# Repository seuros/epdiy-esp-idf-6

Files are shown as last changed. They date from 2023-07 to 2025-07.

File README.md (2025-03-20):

  

EPDiy E-Paper Driver
=======================================

EPDiy is a driver board which talks to affordable E-Paper (or E-Ink) screens, which are usually sold as replacement screens for E-Book readers. Why are they interesting?

* Easy on the eyes and paper-like aesthetics
* No power consumption when not updating
* Sunlight-readable

Ready-made DIY modules for this size and with 4bpp (16 Grayscale) color support are currently quite expensive and / or slow.
The EPDiy controller can drive the bare display modules, e.g. from old e-Readers, which are available for 20$ (small) / 30$ (large) on ebay!
Additionally, since it is based on the ESP32S3 (V7) / ESP32 (V2-V6) microcontroller, it features WiFi and Bluetooth connectivity.

The EPDiy driver board targets a range of E-Paper displays, as shown in the table below.
As the driving method for all matrix-based E-ink displays is more or less the same, only the right connector and timings are needed.
The current V7 board has three different display connectors, other display will require an adapter board.

The controller is optimized for the use with LiPo batteries, featuring a LiPo charger and ultra-low deep sleep current.

This project supports a driver for the ESP-IDF and Arduino. For installation instructions, please refer to the [documentation](https://epdiy.readthedocs.io/en/latest/getting_started.html#getting-your-board).
Note that for epdiy V7, update speeds are significantly lower when using the Arduino IDE, because it does not allow to change
the sub-optimal cache configuration.

Get Inspired
------------

The `examples` directory contains some example applications like a weather station or a screen diagnostic test. 
If you want to build something more useful though, how about:

- A serial terminal for connecting to a raspberry pi: [video](https://cdn.hackaday.io/files/1681937195969312/terminal_demo.mp4) [repository](https://github.com/vroland/epdiy-terminal)]
- A Music Player Daemon (MPD) dashboard: [repository](https://github.com/vroland/epdiy-mpd)]
- An e-Paper picture frame: [video](https://www.youtube.com/watch?v=r7AcNQsSZUw)
- And more to come!

Building It
-----------

On the [EPDiy Hardware Page](https://vroland.github.io/epdiy-hardware/), you'll find a list of all boards and variants, adapters, and helpers.
Next to each board, there are manufacturing files (gerbers), Bill of Materials (BoM), part placement files,
and 3D models ready to use!

demo image

For ordering from JLCPCB for example, ordering is as easy as downloading the zipped gerbers, BoM, and placement file
and uploading them. The process is very similar for other manufacturers, check your vendor's documentation for details.
Don't forget to oder adapters if the board doesn't have connectors for your specific display.

The current latest version is epdiy V7, beased on the ESP32S3. 
Older versions are also available on the hardware page.

#### Contributing Hardware

Want to contribute your own board variant or adapter? 
Check out the [epdiy-hardware repository](https://github.com/vroland/epdiy-hardware) for instructions.

Gettings Started
----------------

For instructions and more information visit the [documentation](https://epdiy.readthedocs.io/en/latest/getting_started.html)!

Join the Discussion
----------------

 -  Matrix Community: +epdiy:matrix.vroland.de
 - Slack: See badge

Displays
--------

|Name |Size |Resolution|Compatible|Connector|Pin count|Compatible since pcb version|Notes
| --: | --: | --: | --: | --: | --: | --: | --: |
| ED060SC4 | 6"  | 800 x 600<br>167 PPI | yes, tested | FH26W-39S-0.3SHW(60) | 39  | v2  | |
|ED097OC4|9.7"|1200 x 825<br>150 PPI|yes, tested|XF2M-3315-1A|33|v2|Cheap, inferior contrast
|ED097TC2|9.7"|1200 x 825<br>150 PPI|yes, tested|XF2M-3315-1A|33|v2|Slightly higher price, better contrast
|ED097OC1|9.7"|1200 x 825<br>150 PPI|yes (should work)|XF2M-3315-1A|33|v2|Cheap, inferior performance
|ED047TC1|4.7"|960 x 540<br>234 PPI|yes, tested|40-pin|40|LILYGO 4.7" EPD|Supported only by 4.7" e-paper board by LILYGO
| ED050SC5 | 5" | 600 x 800<br>200 PPI | yes, tested | THD0510-33CL-GF | 33 | v5 |
| ED050SC3 | 5" | 600 x 800<br>200 PPI | yes (should work) | THD0510-33CL-GF | 33 | v5 |
| ED133UT2 | 13.3" | 1600 x 1200<br>150 PPI | yes, tested | adapter board | 39 | v2 | Adapter Board required, also PENG133D
| ED060XC3 | 6" | 758 x 1024<br>212 PPI | yes, tested | THD0515-34CL-SN | 34 | v5 | Cheapest, good contrast and resolution
| ED060XD4 | 6"  | 758 x 1024<br>212 PPI | yes, tested | THD0515-34CL-SN | 34 | v5 |
| ED060XC5 | 6"  | 758 x 1024<br>212 PPI | yes (should work as ED060XC3) | THD0515-34CL-SN | 34 | v5 |
| ED060XD6 | 6"  | 758 x 1024<br>212 PPI | yes (should work as ED060XC3) | THD0515-34CL-SN | 34 | v5 |
| ED060XH2 | 6"  | 758 x 1024<br>212 PPI | yes (should work as ED060XC3) | THD0515-34CL-SN | 34 | v5 |
| ED060XC9 | 6"  | 758 x 1024<br>212 PPI | yes (should work as ED060XC3) | THD0515-34CL-SN | 34 | v5 |
| ED060KD1 | 6"  | 1072 x 1448<br>300 PPI | yes (should work as ED060XC3) | THD0515-34CL-SN | 34 | v5 |
| ED060KC1 | 6"  | 1072 x 1448<br>300 PPI | yes (should work as ED060XC3) | THD0515-34CL-SN | 34 | v5 |
| ED060SCF | 6" | 600 x 800<br>167 PPI | yes, tested | THD0515-34CL-SN | 34 | v5 | Different flex cable shape
| ED060SCN | 6" | 600 x 800<br>167 PPI | yes (should work as ED060XC3) | THD0515-34CL-SN | 34 | v5 | Different flex cable shape
| ED060SCP | 6" | 600 x 800<br>167 PPI | yes (should work as ED060XC3) | THD0515-34CL-SN | 34 | v5 | Different flex cable shape
| ED060SC7 | 6" | 600 x 800<br>167 PPI | yes (should work) | AXT334124 | 34 | v5 | connector dropped in v6
| ED060SCG | 6"  | 600 x 800<br>167 PPI | yes (should work) | AXT334124 | 34 | v5 | connector dropped in v6
| ED060SCE | 6"  | 600 x 800<br>167 PPI | yes (should work) | AXT334124 | 34 | v5 | connector dropped in v6
| ED060SCM | 6"  | 600 x 800<br>167 PPI | yes (should work) | AXT334124 | 34 | v5 | connector dropped in v6
| ED060SCT | 6"  | 600 x 800<br>167 PPI | yes, tested | AXT334124 | 34 | v5 | connector dropped in v6
| ED078KC1 | 7.8"  | 1872 x 1404<br>300 PPI | yes, tested | FH12-40S-0.5SH | 40 | v7 | 16 data lines

Troubleshooting
---------------

The following list is compiled from past experiences and GitHub issues:
 * **The displayed image displays only part of the image.** Make sure to select the correct display type as described [here](https://epdiy.readthedocs.io/en/latest/getting_started.html#selecting-a-display-type).
 * **The existing image fades / darkens when updating a partial screen region.** Make sure the VCOM voltage is [calibrated](https://epdiy.readthedocs.io/en/latest/getting_started.html#calibrate-vcom) for your specific display.
 * **The second third of the image is replaced with the last third.** This seems to be a timing issue we could not yet quite figure out the reason for. For a workarround or suggestions please [join the discussion](https://github.com/vroland/epdiy/issues/15).
 * **The ESP does not boot correctly when external periperals are connected.** Make sure not to pull GPIO12 high during boot, as it is a strapping pin internal voltage selection (https://github.com/vroland/epdiy/issues/17).
 * **The ESP power consumption in deep sleep is too high.** Add `rtc_gpio_isolate(GPIO_NUM_12);` to your solution. See also [Configuring IOs (Deep-sleep Only)](https://docs.espressif.com/projects/esp-idf/en/latest/esp32/api-reference/system/sleep_modes.html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).

LilyGo Boards
---------------
There are several differences with these boards.
One particular one is the way the LilyGo handles power to the display the official lilygo code has two states.
This is now handled in epdiy in a different way to the lilygo code.
**epd_poweroff()** completely turns the power off to the display and the other peripherals of the lilygo.
The new function **epd_powerdown()** keeps the peripherals on (this allows the touch functions to continue to work). 
**epd_poweroff() should allways be called before sleeping the system**
You can still use touch to wake the screen with the following.
In Arduino it works like this.
`epd_poweroff();`

 `epd_deinit();`

 `esp_sleep_enable_ext1_wakeup(GPIO_SEL_13, ESP_EXT1_WAKEUP_ANY_HIGH);`

 `esp_deep_sleep_start();`

More on E-Paper Displays
------------------------

 * List of E-Paper devices and their screens: https://e-ink-reader.ru/chg_dsp_en.php (thanks, @mcer12)
 * Reverse engineering of display pins, possible starting point for alternative drivers: https://linux-sunxi.org/PocketBook_Touch_Lux_3 (thanks, @mcer12)
 * Reverse engineering and explanation on driving EPDs: http://essentialscrap.com/eink/index.html
 * Earlier take on driving 6" EPDs with an ESP32, basis of original power circuit: http://spritesmods.com/?art=einkdisplay&page=1
 * Related Hackaday projects: https://hackaday.io/project/21607 https://hackaday.io/project/11537

If you know any other useful resources or have suggestions, please comment on #31!

Hackaday Project
----------------

For more details, see the project page on Hackaday: https://hackaday.io/project/168193-epdiy-976-e-paper-controller

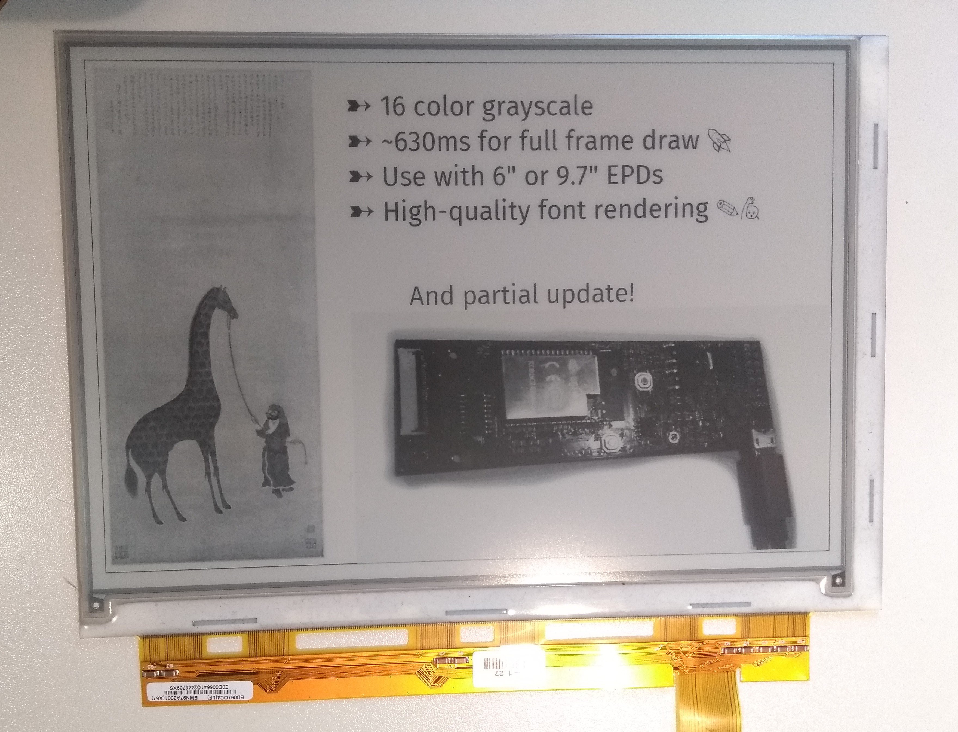
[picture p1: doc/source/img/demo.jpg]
demo image

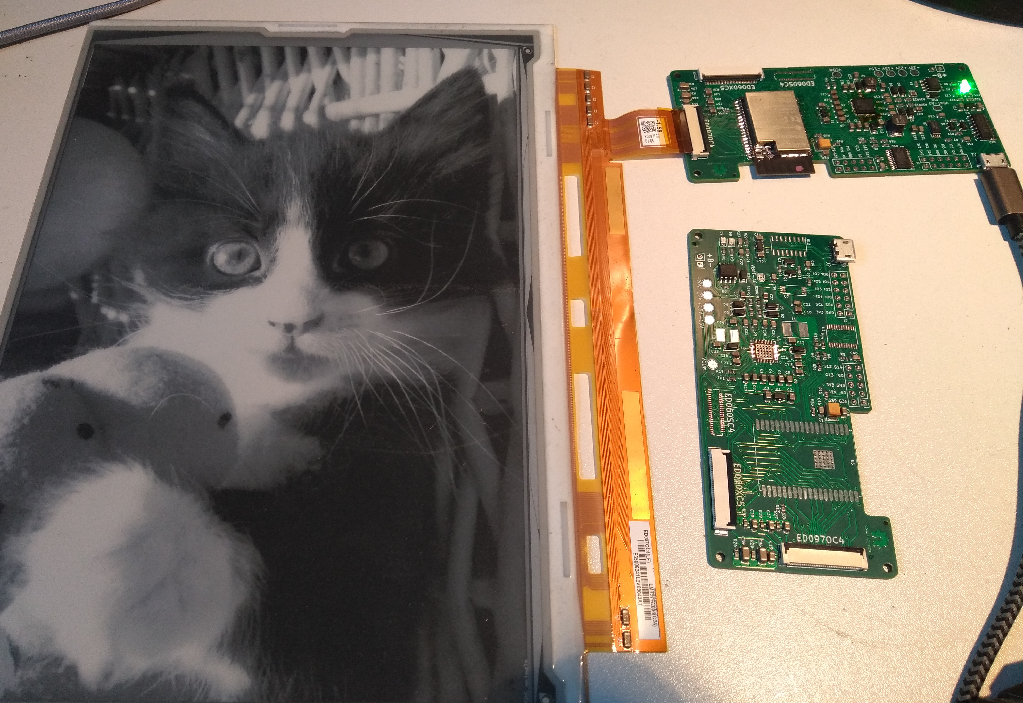
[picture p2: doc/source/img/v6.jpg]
board front


Licenses
--------

The weather example is Copyright (c) David Bird 2018 (except for minor modifications). Please refer to `examples/weather/README.md` for details.

The board and schematic are licensed under a  <a rel="license" href="https://creativecommons.org/licenses/by-sa/4.0/">Creative Commons Attribution-ShareAlike 4.0 International License</a>.

Firmware and remaining examples are licensed under the terms of the GNU Lesser GPL version 3.
Utilities are licensed under the terms of the MIT license.

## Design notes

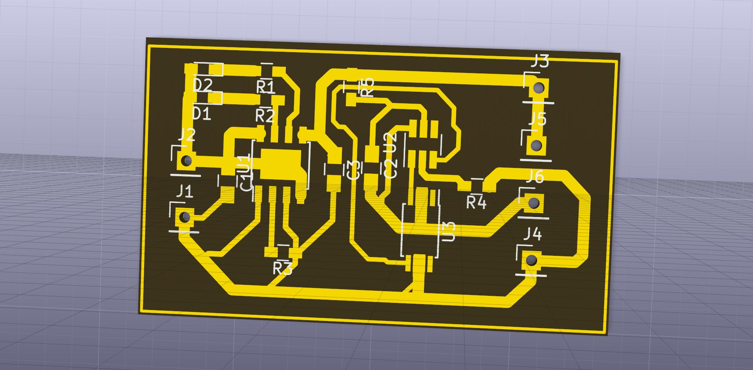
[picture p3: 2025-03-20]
hardware/epaper-breakout/tp4056/out/charger_stepup1.jpg

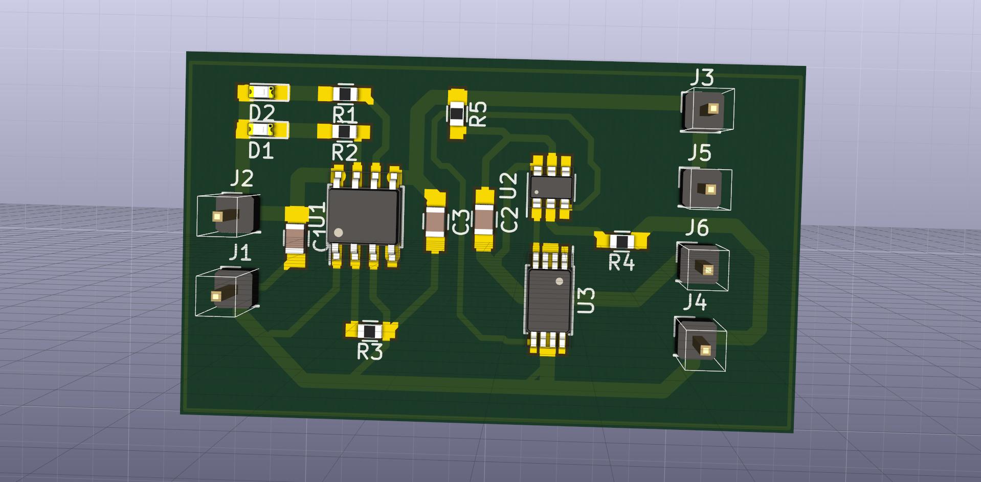
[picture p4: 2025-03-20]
hardware/epdiy-v7/tp4056/out/charger_stepup2.jpg

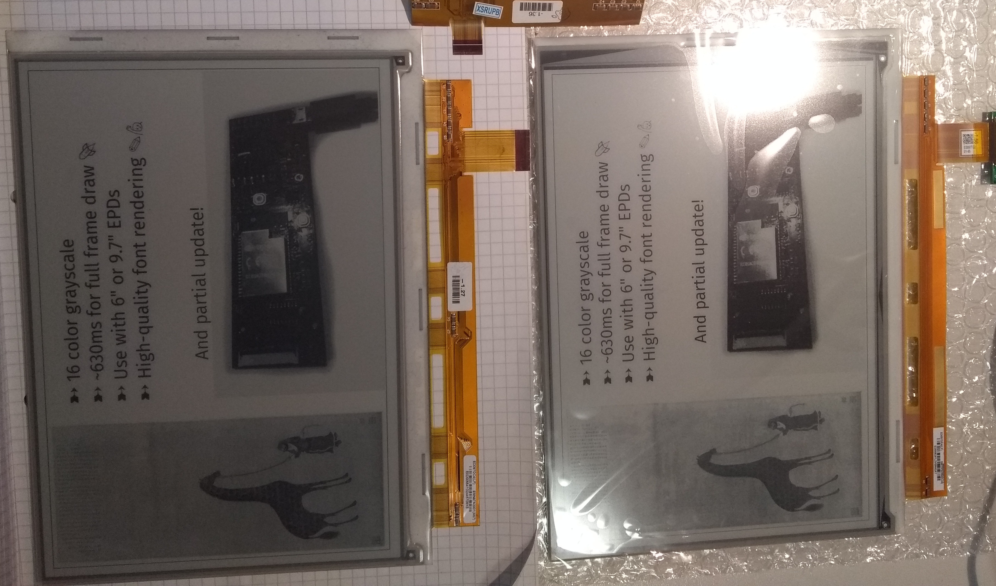
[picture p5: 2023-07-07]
doc/source/img/ed097tc2.jpg

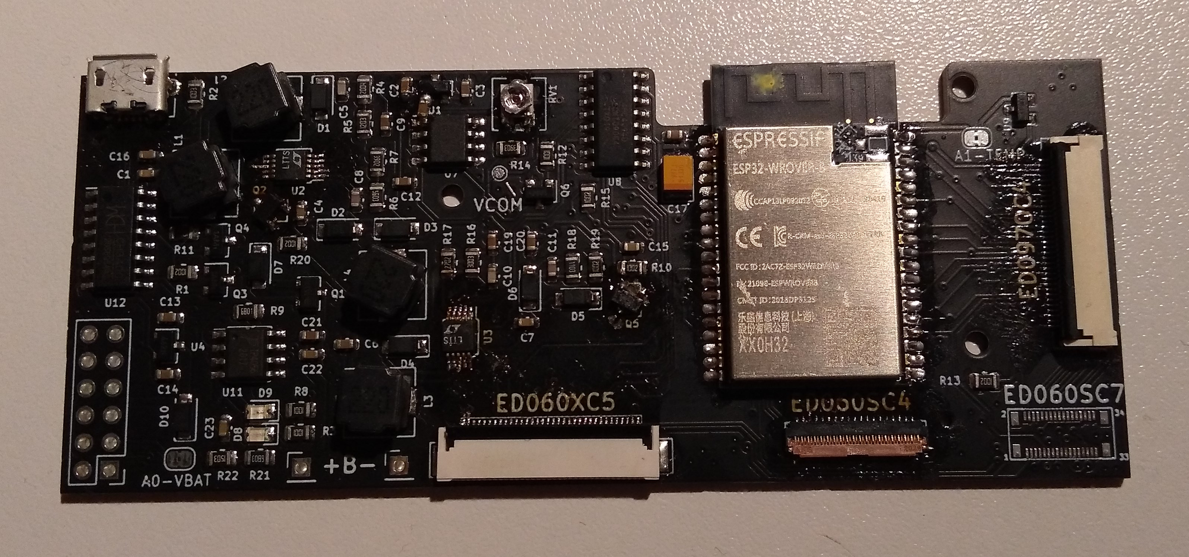
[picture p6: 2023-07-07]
doc/source/img/board_p1.jpg

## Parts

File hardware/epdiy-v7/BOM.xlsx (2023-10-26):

Designator | Footprint | Comment | JLCPCB Part #
R15,R1,R11,R10,R4,R6,R14,R16,R33,R32 | R_0603_1608Metric | 10k | C25804
Q3,Q4 | SOT-23 | MMBT3904 | C20526
C3,C19,C9,C32,C12,C2,C16 | C_0805_2012Metric | 10uF | C28323
C22,C23,C30,C29,C15,C40,C42,C39 | C_0805_2012Metric | 100nF | C49678
D9 | LED_0805_2012Metric | LED RED | C84256
R3 | R_0603_1608Metric | 2.4k | C22940
R8 | R_0603_1608Metric | 1k | C21190
D8 | LED_0805_2012Metric | LED GREEN | C2297
C18,C13,C14 | C_0805_2012Metric | 1uF | C28323
C11,C5,C31,C8,C24,C1,C7,C4,C28,C26 | C_0805_2012Metric | 4.7uF | C1779
C34,C36 | C_1206_3216Metric | 1uF/50V | C1848
C35,C37,C38 | C_0805_2012Metric | 1uF/25V | C28323
R5 | R_0603_1608Metric | 0 | C21189
R18 | R_0603_1608Metric | 43k | C23172
R26,R27,R28,R29 | R_0603_1608Metric | 47k | C25819
TH1 | R_0603_1608Metric | 10k/3380K | C76589
U2 | TSSOP-24_4.4x7.8mm_P0.65mm | PCA9535PW | C255606
C17 | CP_EIA-3528-15_AVX-H | 100uF | C16133
R19,R23 | R_0603_1608Metric | 1M | C22935
L2 | L_Taiyo-Yuden_NR-40xx_HandSoldering | 2.2uH | C92959
L1 | L_Taiyo-Yuden_NR-50xx_HandSoldering | 4.7uH | C222947
R24 | R_0603_1608Metric | 47.5k | C25819
R20 | R_0603_1608Metric | 52.3k | C23196
U3 | TPS651851RSLR | TPS651851RSLR | C139292
C6,C10 | C_0805_2012Metric | 22uF | C45783
D6,D5,D3,D2,D4,D1,D7 | D_SOD-123 | MBR0540 | C21353
C27,C33 | C_0805_2012Metric | 2.2uF | C49217
C20,C25 | C_0805_2012Metric | 10nF | C1710
R30,R31 | R_0603_1608Metric | 100k | C25803
R22 | R_0603_1608Metric | 150k | C22807
R21 | R_0603_1608Metric | 680k | C25822
U11 | TP4056_SOP-8-PP | TP4056 | C16581
D10 | D_SOD-123 | 1N5817 | C8598
R9 | R_0603_1608Metric | 3.83k | C103591
U5 | SOT-23-3 | XC6206PxxxMR | C5446
U4 | SOT-666 | USBLC6-2P6 | C2827693
U6 | Hirose_FH12-40S-0.5SH_1x40-1MP_P0.50mm_Horizontal | ED078KH6 | C202114
Q1 | SOT-23 | AO3401A | C15127
J9,J1 | USB_C_Receptacle_HRO_TYPE-C-31-M-12 | USB_C_Receptacle_USB2.0 | C165948
C21,C41 | C_0805_2012Metric | 12pF | C1792
U7 | SOIC-8_3.9x4.9mm_P1.27mm | PCF8563T | C7440
R7,R13,R2,R12 | R_0603_1608Metric | 5.1k | C23186
J8 | HRS_FH26W-39S-0.3SHW(60) | ED133UT2 | C92280
U1 | TSOT-23-5 | RT9080-33GJ5 | C841192
J4 | FH1233S05SH55 | XF2M-3315-1A | C597986
U8 | ESP32-S3-WROOM-1 | ESP32-S3-WROOM-1 | C2913202
U9 | SOIC-16_3.9x9.9mm_P1.27mm | CH340C | C7464026
Y1 | Crystal_SMD_3215-2Pin_3.2x1.5mm | 32.768K | C32346

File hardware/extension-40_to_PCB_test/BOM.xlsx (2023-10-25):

Designator | Footprint | Comments | JLCPCB Part #
R8,R7,R22,R14,R9,R4,R1,R20,R21,R12,R19,R11,R18,R6,R3,R23,R2,R10,R16,R15,R13,R17,R5 | R_0603_1608Metric | 2.4k | C22940
D7,D1,D15,D11,D14,D8,D9,D13,D4,D12,D5,D2,D0,D6,D10,D3 | LED_0805_2012Metric | LED GREEN | C2297
CKV1,XSTL1,OE1,STV1,EP_MODE1,XCL1,LEH1 | LED_0805_2012Metric | LED RED | C84256
R25,R24 | R_0603_1608Metric | 33k | C4216
J1 | XKTF005-SD | XKTF-005 | C2689687
U1 | FH1240S05SH55 | ED078KH6 | C202114
RN1 | SMT_F392JTCE_UNR_SD-pullup | R_arr 35K Ω | C425297

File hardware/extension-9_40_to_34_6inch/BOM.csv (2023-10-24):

Id | Designator | Footprint | Quantity | Designation | Supplier and ref
1 | J1 | FH1233S05SH55 | 1 | XF2M-3315-1A
2 | U1,U3 | X05A20H34G | 2 | ED060XC5
3 | U2 | FH1240S05SH55 | 1 | ED078KH6

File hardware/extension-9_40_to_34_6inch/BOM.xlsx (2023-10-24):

Designator | Footprint | Comments | JLCPCB Part #
J1 | FH1233S05SH55 | XF2M-3315-1A | C597986
U1,U3 | X05A20H34G | ED060XC5 | C528053
U2 | FH1240S05SH55 | ED078KH6 | C202114

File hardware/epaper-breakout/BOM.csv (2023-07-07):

Comment | Designator | Footprint | LCSC
22uF | C6,C10 | Capacitor_SMD:C_0805_2012Metric | C45783
4.7uF | C1,C4,C5,C7,C8,C11,C24,C26,C28,C31 | Capacitor_SMD:C_0805_2012Metric | C1779
100nF | C15,C16,C21,C22,C23,C29,C30,C39,C40 | Capacitor_SMD:C_0805_2012Metric | C49678
100uF | C17 | Capacitor_Tantalum_SMD:CP_EIA-3528-15_AVX-H | C16133
1uF | C13,C14,C18 | Capacitor_SMD:C_0805_2012Metric | C28323
10uF | C2,C3,C9,C12,C19,C32 | Capacitor_SMD:C_0805_2012Metric | C15850
10nF | C20,C25 | Capacitor_SMD:C_0805_2012Metric | C1710
2.2uF | C27,C33 | Capacitor_SMD:C_0805_2012Metric | C49217
1uF/50V | C34,C36 | Capacitor_SMD:C_1206_3216Metric | C1848
1uF/25V | C35,C37,C38 | Capacitor_SMD:C_0805_2012Metric | C28323
1N5817 | D7,D10 | Diode_SMD:D_SOD-123 | C8598
MBR0540 | D1,D2,D3,D4,D5,D6 | Diode_SMD:D_SOD-123 | C21353
LED GREEN | D8 | LED_SMD:LED_0805_2012Metric | C2297
LED RED | D9 | LED_SMD:LED_0805_2012Metric | C84256
MountingHole | H1,H2,H3 | MountingHole:MountingHole_2.2mm_M2
XF2M-3315-1A | J1 | epaper-breakout:CONN_ED097OC4 | C231420
C10418 | J2 | epaper-breakout:USB_Micro-B_A01SB141B1-067 | C10418
Conn_02x05_Counter_Clockwise | J3 | Connector_PinHeader_2.54mm:PinHeader_2x05_P2.54mm_Vertical
ED060SC4 | J4 | epaper-breakout:HRS_FH26W-39S-0.3SHW(60) | C519255
Conn_01x02_Female | J5 | Connector_PinHeader_2.54mm:PinHeader_1x02_P2.54mm_Vertical
Conn_01x12 | J7 | Connector_PinHeader_2.54mm:PinHeader_2x06_P2.54mm_Vertical
Jumper | JP_BAT1 | Jumper:SolderJumper-2_P1.3mm_Bridged2Bar_RoundedPad1.0x1.5mm
4.7uH | L1 | Inductor_SMD:L_Taiyo-Yuden_NR-50xx_HandSoldering | C222947
2.2uH | L2 | Inductor_SMD:L_Taiyo-Yuden_NR-40xx_HandSoldering | C92959
MMBT3904 | Q3,Q4 | Package_TO_SOT_SMD:SOT-23 | C20526
10k | R1,R4,R6,R10,R11,R13,R14,R15,R16,R25 | Resistor_SMD:R_0603_1608Metric | C25804
43k | R18 | Resistor_SMD:R_0603_1608Metric | C23172
400 | R2 | Resistor_SMD:R_0603_1608Metric | C23151
52.3k | R20 | Resistor_SMD:R_0603_1608Metric | C23196
680k | R21 | Resistor_SMD:R_0603_1608Metric | C25822
150k | R22 | Resistor_SMD:R_0603_1608Metric | C22807
1M | R19,R23 | Resistor_SMD:R_0603_1608Metric | C22935
47.5k | R24 | Resistor_SMD:R_0603_1608Metric | C25819
47k | R26,R27,R28,R29 | Resistor_SMD:R_0603_1608Metric | C25819
100k | R7,R30 | Resistor_SMD:R_0603_1608Metric | C25803
0 | R5 | Resistor_SMD:R_0603_1608Metric
1k | R3,R8 | Resistor_SMD:R_0603_1608Metric | C21190
6.8k | R9 | Resistor_SMD:R_0603_1608Metric | C23212
10k/3380K | TH1 | Resistor_SMD:R_0603_1608Metric | C76589
+22V | TP1 | TestPoint:TestPoint_Pad_D2.5mm
-15V | TP2 | TestPoint:TestPoint_Pad_D2.5mm
-20V | TP3 | TestPoint:TestPoint_Pad_D2.5mm
+15V | TP4 | TestPoint:TestPoint_Pad_D2.5mm
VCOM | TP5 | TestPoint:TestPoint_Pad_D2.5mm
MCP1700-3302E_SOT23 | U1 | Package_TO_SOT_SMD:SOT-23 | C39051
TP4056 | U11 | epaper-breakout:TP4056_SOP-8-PP | C16581
CH340C | U12 | Package_SO:SOIC-16_3.9x9.9mm_P1.27mm | C84681
PCA9535PW | U2 | Package_SO:TSSOP-24_4.4x7.8mm_P0.65mm | C255606
TPS651851RSLR | U3 | tps65185:TPS651851RSLR | C139292
XC6206PxxxMR | U4 | Package_TO_SOT_SMD:SOT-23 | C5446
ESP32-WROVER | U5 | esp32-wrover:ESP32-WROVER | C503591
ED060XC5 | U6 | epaper-breakout:X05A20H34G | C528053
TPS2113APW | U7 | epaper-breakout:TPS2113APW | C130052

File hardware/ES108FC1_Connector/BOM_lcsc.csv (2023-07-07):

Comment | Designator | Footprint | LCSC
Conn_02x03_Odd_Even | J1 | Connector_PinHeader_2.54mm:PinHeader_2x03_P2.54mm_Vertical
ES108FC1 | J2 | epaper-breakout:ES108FC1 | C2880696
ED078KH6 | U1 | epaper-breakout:Hirose_FH12-40S-0.5SH_mirrored | C202114

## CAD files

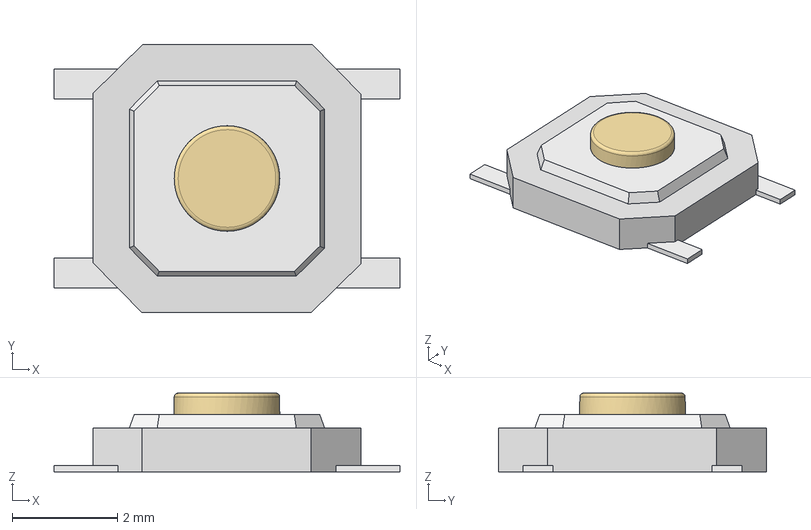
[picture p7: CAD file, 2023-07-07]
hardware/epaper-breakout/3dmodels/Tactal Switch - SMD (5mmx 5mmx1.5mm).stp
6.58 x 5.10 x 1.50 mm

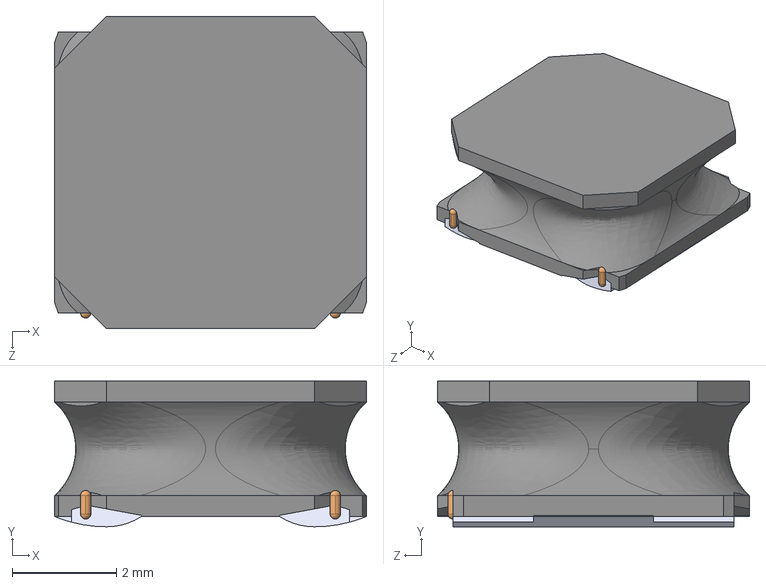
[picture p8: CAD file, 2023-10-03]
hardware/epdiy-v7/3dmodels/L-40xx.STEP
6.00 x 2.80 x 6.00 mm

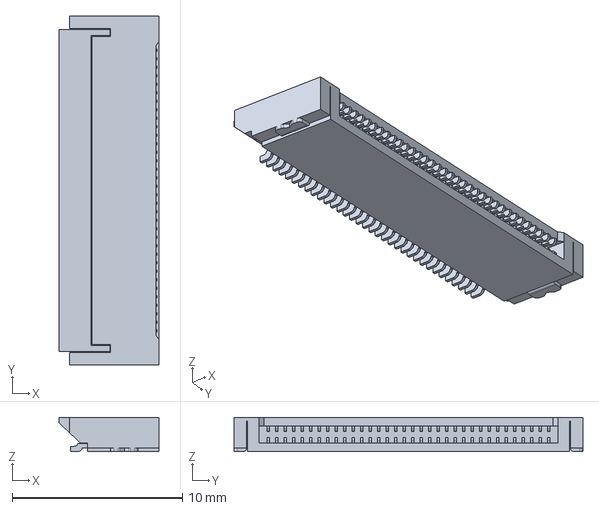
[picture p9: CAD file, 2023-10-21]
hardware/extension-40_to_PCB_test/3d/X05A20H34G.step
5.90 x 20.5 x 2.00 mm

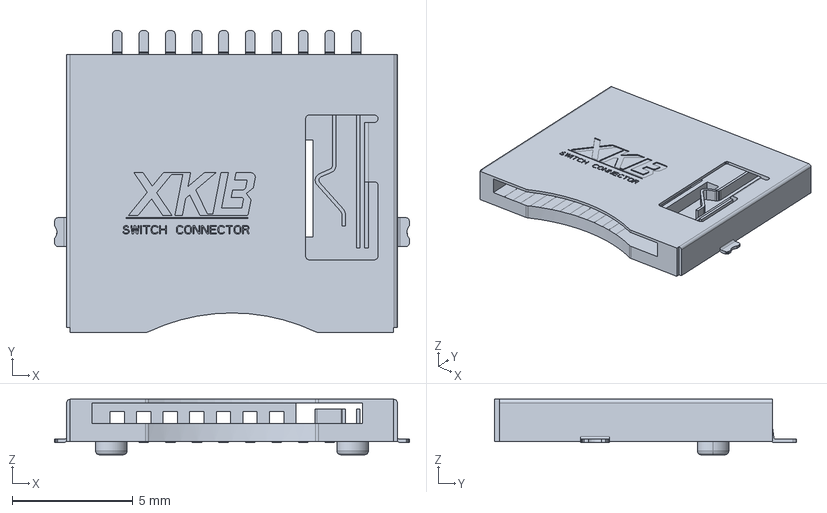
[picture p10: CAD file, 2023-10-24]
hardware/extension-40_to_PCB_test/component/3d/XKTF-005-SD.stp
14.7 x 12.5 x 2.30 mm

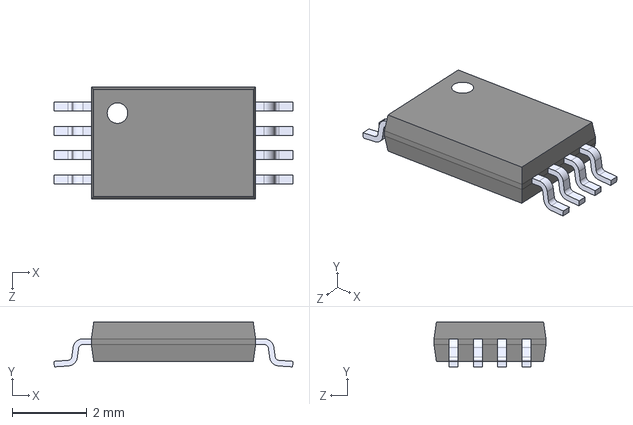
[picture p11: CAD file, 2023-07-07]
hardware/epdiy-v7/3dmodels/tps2113apwr.step
6.40 x 1.20 x 3.00 mm

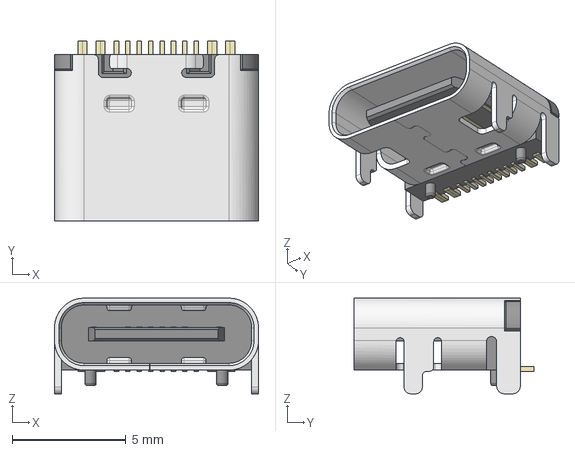
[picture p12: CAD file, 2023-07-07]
hardware/epdiy-v7/3dmodels/USB_TYPE-C-31-M-12.step
8.95 x 7.90 x 4.20 mm

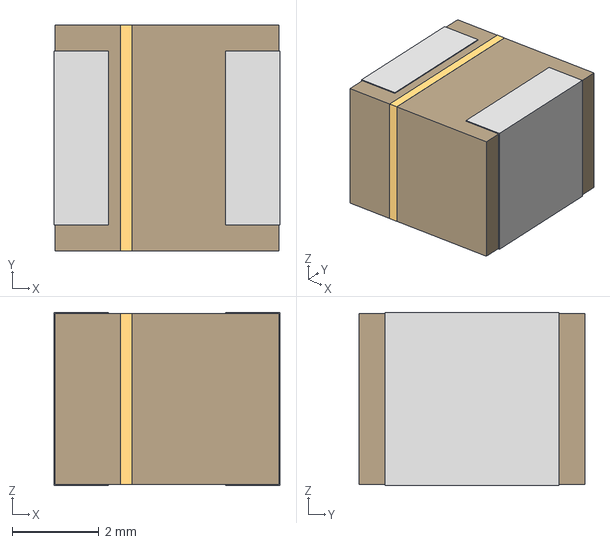
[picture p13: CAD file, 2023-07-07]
hardware/epdiy-v7/3dmodels/IND_0S282MT_SNL.step
5.21 x 5.21 x 3.99 mm

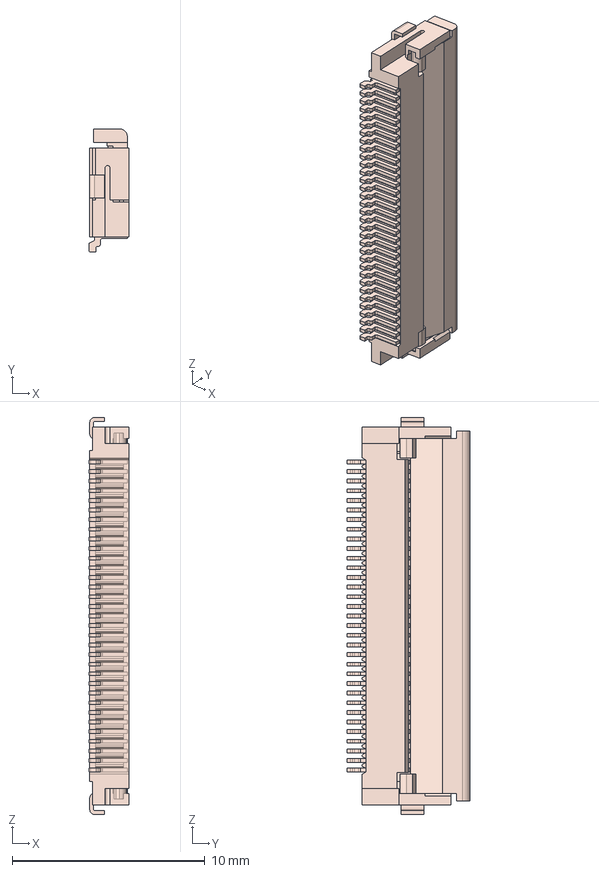
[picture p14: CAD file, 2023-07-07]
hardware/epdiy-v7/3dmodels/FH12-33S-0.5SH.step
2.10 x 6.40 x 20.6 mm

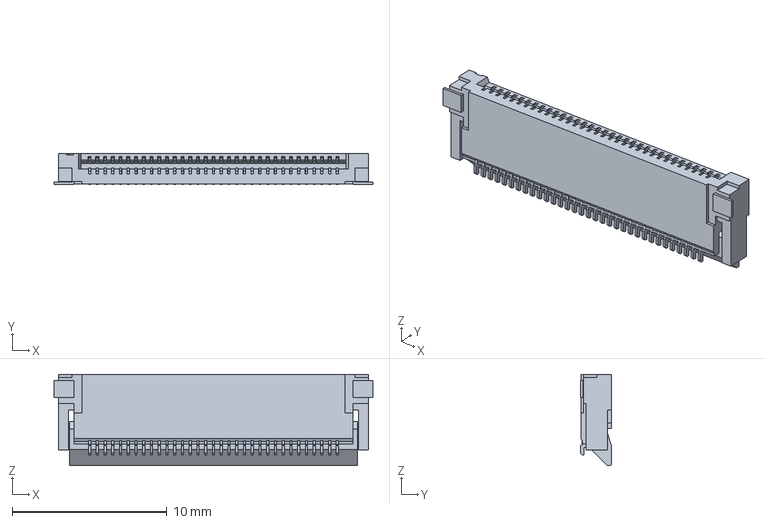
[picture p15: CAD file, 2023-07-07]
hardware/epdiy-v7/3dmodels/xf2m-3315-1a.step
20.6 x 2.00 x 5.90 mm

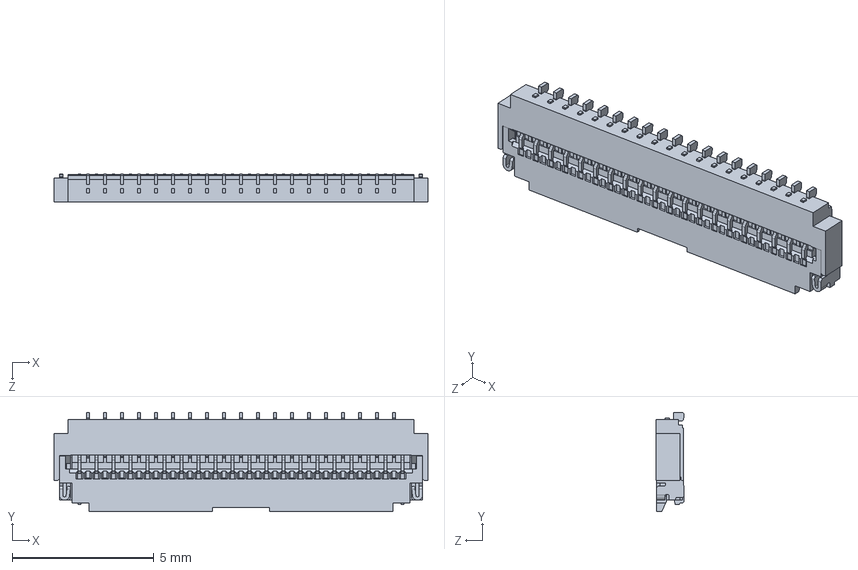
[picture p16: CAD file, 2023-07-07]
hardware/epdiy-v7/3dmodels/HRS-FH26W-39S.STEP
13.2 x 3.50 x 1.00 mm

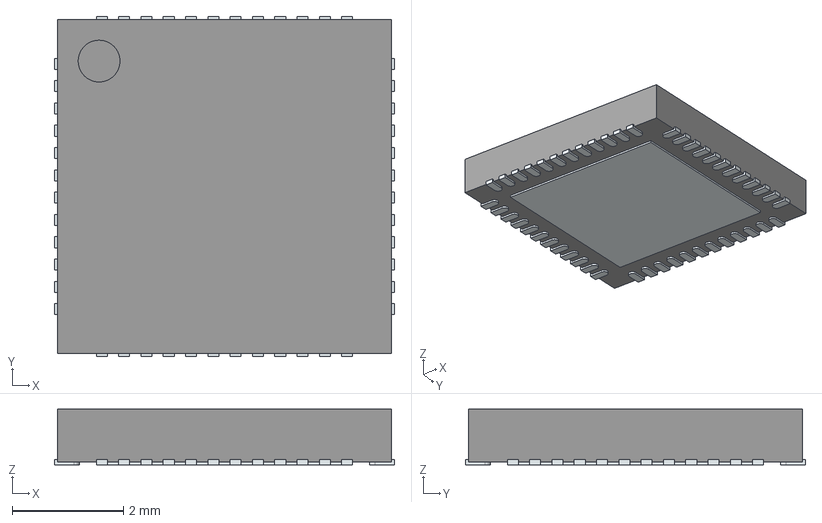
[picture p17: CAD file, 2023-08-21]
hardware/epdiy-v7/3dmodels/TPS651851RSLR.step
6.10 x 6.10 x 1.00 mm
ThermalPin
PinsArrayLR
PinsArrayTB

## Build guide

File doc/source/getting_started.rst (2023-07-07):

.. _getting_started:

Getting Started
===============

Getting your Board
------------------

At the current point in time, there is no official way to buy an epdiy board.
Fortunately, it is quite easy to order your own. There are many PCB prototype services
that will manufacture boards for a low price.

To use one of those services, upload the "Gerber files", usually provided as a zip file,
to the service.
Please consult the README of the epdiy repository for a link to the gerber files for the current revision.
Some services also offer automated assembly for all or a subset of components.
Usually, you will have to upload a bill of materials (BOM) and a placement file.
Both are provided in the `hardware/epaper-breakout` directory.

Choosing and Finding Parts
~~~~~~~~~~~~~~~~~~~~~~~~~~

The parts needed to assemble the epdiy board are listed in the `BOM.csv` file.
Commodity parts like resistors, capacitors, coils and diodes are interchangable, as long as they
fit the footprint. 
When in doubt, use the parts listed in the BOM file.

However, some parts are not as common, especially the connectors. 
Most of them can be found on sites like eBay or AliExpress. 

Tips:
    - Use the WROVER-B module instead of other WROVER variants.
      This module exhibits a low deep sleep current and is proven to work.
    - The LT1945 voltage booster seems to be out of stock with some distributors,
      but they are available cheaply from AliExpress.

Calibrate VCOM
--------------

EPaper displays use electrical fields to drive colored particles.
One of the required voltages, VCOM (Common Voltage) is display-dependent
and must be calibrated for each display individually.

Fortunately, the VCOM voltage is usually printed on the display, similar to this:

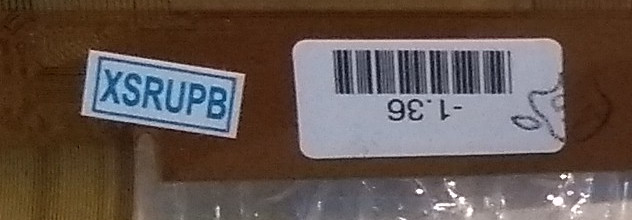
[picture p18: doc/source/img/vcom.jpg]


The VCOM value is usually between -1V and -3V. 

For the v6 board, you can enter the desired VCOM value in :code:`make menuconfig`.
No interaction is required.

For the older models, use the trimmer marked :code:`RV1`.
You can measure the VCOM on the VCOM test pad (if your board has one) or directly
at the amplifier:

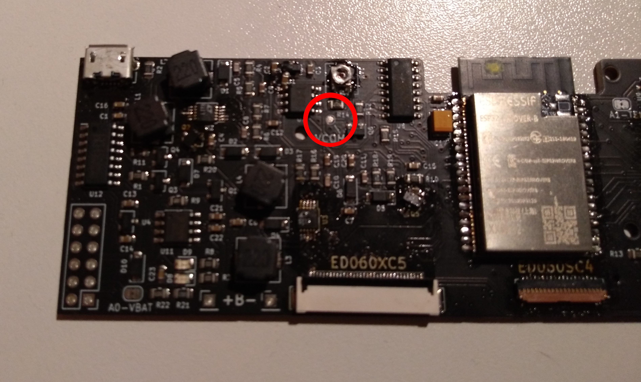
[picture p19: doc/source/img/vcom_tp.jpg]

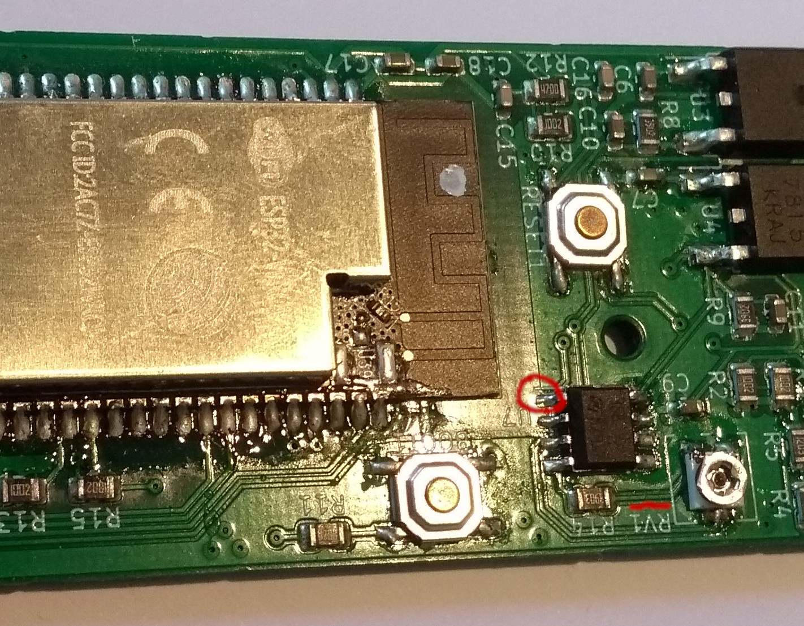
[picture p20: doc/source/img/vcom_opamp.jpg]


.. note::
    
    Although most boards do not have it yet, image quality for partial updates can be improved by adding a (at least) 4.7uF capacitor between VCOM and GND. 
    When adding this capacitor, take care with the polarity as VCOM is negative!

Flashing the demo
-----------------

First, connect you board with the computer. In the output of :code:`lsusb` you should find something like:
::

    Bus 001 Device 048: ID 1a86:7523 QinHeng Electronics HL-340 USB-Serial adapter

This means the serial adapter is working and there a serial like :code:`/dev/ttyUSB0` should appear.

Next, make sure you have the `Espressif IoT Development Framework <https://github.com/espressif/esp-idf>`_ installed. 
The current stable (and tested) version is 4.0.
For instructions on how to get started with the IDF, please refer to their `documentation <https://docs.espressif.com/projects/esp-idf/en/stable/get-started/>`_.

Then, clone the :code:`epdiy` git repository (and its submodules):
::

    git clone --recursive https://github.com/vroland/epdiy

Now, (after activating the IDF environment) you should be able to build the demo:
::

    cd examples/demo/
    idf.py build

Hold down the :code:`BOOT` button on your board, while quickly pressing the :code:`RESET` button. 
The ESP module is now in boot mode. 
Upload the demo program to the board with
::

    idf.py flash -b 921600 && idf.py monitor

Pressing :code:`RESET` a second time should start the demo program, which will
output some information on the serial monitor.

With the **board power turned off**, connect your display. 
Power on the board.
You should now see the demo output on your display.

Use with esp-idf
----------------

The neccessary functionality for driving an EPD display is encapsulated in the :code:`components/epd_driver` IDF component.
To use it in you own project, simply copy the :code:`epd_driver` folder to your project-local :code:`components` directory.
The component sould be automatically detected by the framework, you can now use
::

    #include "epd_driver.h"

to use the EPD driver's :ref:`pub_api`.

Selecting a Display Type
~~~~~~~~~~~~~~~~~~~~~~~~

To select the display type you want to use for the project (see :ref:`display_types`), run
::

    idf.py menuconfig

And navigate to :code:`Component config -> E-Paper driver -> Display Type`, select the appropriate option and save the configuration. You can use the defines
::

    EPD_WIDTH
    EPD_HEIGHT
    CONFIG_EPD_DISPLAY_TYPE_ED097OC4
    CONFIG_EPD_DISPLAY_TYPE_ED060SC4
    CONFIG_EPD_DISPLAY_TYPE_...

to make your code portable.

Enable SPI RAM
~~~~~~~~~~~~~~~~~~~~~~~~
The ESP32-WROVER-B comes with an additional 8MB external PSRAM, where the :code:`epd_driver` is going to store ~2MB for its internal frame buffers. 
Since it is dynamically allocated from the heap, and the built-in SRAM of ~160KB is insufficient, we need to enable external SPI RAM first.

Open the :code:`menuconfig` again (see above) and navigate to :code:`Component config -> ESP32-Specific -> Support for external, SPI-connected RAM` and enable it.

Use with Arduino
----------------

Epdiy can be used as an Arduino library. Additionally, epdiy comes with board definitions for its supported boards, which must be installed separately. 
To install epdiy to work with the Arduino IDE (>= 1.8), follow the steps below:

1. Download / Clone the epdiy repository into your arduino libraries folder.
2. Install the `arduino-esp32 core <https://github.com/espressif/arduino-esp32#installation-instructions>`_. 
3. Due to a limitation in the arduino-esp32 core, the epdiy board definitions must be installed manually. To do that, copy the :code:`boards.local.txt` file that comes with epdiy to the directory you installed the esp32 core in.

    * On Linux, this will be somewhere in :code:`~/Arduino/hardware/esp32/esp32`.
    * On Windows, this will look something like :code:`C:/Users/<username>/Documents/Arduino/hardware/espressif/esp32` or a similar path in AppData.

   You can also search the Arduino logs to find the arduino-esp32 install directory.

   If you have the correct directory, there should be a :code:`boards.txt` file in it. Copy the :code:`boards.local.txt` in this directory.
4. Re-start the Arduino IDE. The Epdiy boards should now show up among the other ESP32 boards.
5. Select your epdiy-compatible board. You can now select your display from the board menu.
6. Try out an example sketch! Some of them are not very Arduino-Style yet, but they should help getting you started. 

Alternatively, it is possible to use the `Arduino APIs as an IDF component <https://github.com/espressif/arduino-esp32/blob/master/docs/esp-idf_component.md>`_,
which allows you to use the Arduino ecosystem (Except for a different build process).

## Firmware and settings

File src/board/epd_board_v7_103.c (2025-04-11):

#include <stdint.h>
#include "epd_board.h"
#include "epdiy.h"

#include "../output_common/render_method.h"
#include "../output_lcd/lcd_driver.h"
#include "esp_log.h"
#include "pca9555.h"
#include "tps65185.h"

#include <driver/gpio.h>
#include <driver/i2c.h>
#include <sdkconfig.h>

// Make this compile von the ESP32 without ifdefing the whole file
#ifndef CONFIG_IDF_TARGET_ESP32S3
#define GPIO_NUM_40 -1
#define GPIO_NUM_41 -1
#define GPIO_NUM_42 -1
#define GPIO_NUM_43 -1
#define GPIO_NUM_44 -1
#define GPIO_NUM_45 -1
#define GPIO_NUM_46 -1
#define GPIO_NUM_47 -1
#define GPIO_NUM_48 -1
#endif

#define CFG_SCL GPIO_NUM_40
#define CFG_SDA GPIO_NUM_39
#define CFG_INTR GPIO_NUM_38
#define EPDIY_I2C_PORT I2C_NUM_0

#define CFG_PIN_OE (PCA_PIN_PC10 >> 8)
#define CFG_PIN_MODE (PCA_PIN_PC11 >> 8)
#define __CFG_PIN_STV (PCA_PIN_PC12 >> 8)
#define CFG_PIN_PWRUP (PCA_PIN_PC13 >> 8)
#define CFG_PIN_VCOM_CTRL (PCA_PIN_PC14 >> 8)
#define CFG_PIN_WAKEUP (PCA_PIN_PC15 >> 8)
#define CFG_PIN_PWRGOOD (PCA_PIN_PC16 >> 8)
#define CFG_PIN_INT (PCA_PIN_PC17 >> 8)

#define D15 GPIO_NUM_5
#define D14 GPIO_NUM_6
#define D13 GPIO_NUM_7
#define D12 GPIO_NUM_15
#define D11 GPIO_NUM_16
#define D10 GPIO_NUM_17
#define D9 GPIO_NUM_18
#define D8 GPIO_NUM_8

#define D7 GPIO_NUM_9
#define D6 GPIO_NUM_10
#define D5 GPIO_NUM_11
#define D4 GPIO_NUM_12
#define D3 GPIO_NUM_13
#define D2 GPIO_NUM_14
#define D1 GPIO_NUM_21
#define D0 GPIO_NUM_47

/* Control Lines */
#define CKV GPIO_NUM_42
#define STH GPIO_NUM_45
#define LEH GPIO_NUM_48
#define STV GPIO_NUM_41

/* Edges */
#define CKH GPIO_NUM_4

typedef struct {
    i2c_port_t port;
    bool pwrup;
    bool vcom_ctrl;
    bool wakeup;
    bool others[8];
} epd_config_register_t;

/** The VCOM voltage to use. */
static int vcom = 1600;

static epd_config_register_t config_reg;

static bool interrupt_done = false;

static void IRAM_ATTR interrupt_handler(void* arg) {
    interrupt_done = true;
}

static lcd_bus_config_t lcd_config = {
    .clock = CKH,
    .ckv = CKV,
    .leh = LEH,
    .start_pulse = STH,
    .stv = STV,
    .data[0] = D0,
    .data[1] = D1,
    .data[2] = D2,
    .data[3] = D3,
    .data[4] = D4,
    .data[5] = D5,
    .data[6] = D6,
    .data[7] = D7,
    .data[8] = D8,
    .data[9] = D9,
    .data[10] = D10,
    .data[11] = D11,
    .data[12] = D12,
    .data[13] = D13,
    .data[14] = D14,
    .data[15] = D15,
};

static void epd_board_init(uint32_t epd_row_width) {
    gpio_hold_dis(CKH);  // free CKH after wakeup

    i2c_config_t conf;
    conf.mode = I2C_MODE_MASTER;
    conf.sda_io_num = CFG_SDA;
    conf.scl_io_num = CFG_SCL;
    conf.sda_pullup_en = GPIO_PULLUP_ENABLE;
    conf.scl_pullup_en = GPIO_PULLUP_ENABLE;
    conf.master.clk_speed = 100000;
    conf.clk_flags = 0;
    i2c_param_config(EPDIY_I2C_PORT, &conf);

    i2c_driver_install(EPDIY_I2C_PORT, I2C_MODE_MASTER, 0, 0, 0);

    config_reg.port = EPDIY_I2C_PORT;
    config_reg.pwrup = false;
    config_reg.vcom_ctrl = false;
    config_reg.wakeup = false;
    for (int i = 0; i < 8; i++) {
        config_reg.others[i] = false;
    }

    gpio_set_direction(CFG_INTR, GPIO_MODE_INPUT);
    gpio_set_intr_type(CFG_INTR, GPIO_INTR_NEGEDGE);

    ESP_ERROR_CHECK(gpio_install_isr_service(ESP_INTR_FLAG_EDGE));

    ESP_ERROR_CHECK(gpio_isr_handler_add(CFG_INTR, interrupt_handler, (void*)CFG_INTR));

    // set all epdiy lines to output except TPS interrupt + PWR good
    ESP_ERROR_CHECK(pca9555_set_config(config_reg.port, CFG_PIN_PWRGOOD | CFG_PIN_INT, 1));

    const EpdDisplay_t* display = epd_get_display();

    LcdEpdConfig_t config = {
        .pixel_clock = display->bus_speed * 1000 * 1000,
        .ckv_high_time = 60,
        .line_front_porch = 4,
        .le_high_time = 4,
        .bus_width = display->bus_width,
        .bus = lcd_config,
    };
    epd_lcd_init(&config, display->width, display->height);
}

static void epd_board_deinit() {
    epd_lcd_deinit();

    ESP_ERROR_CHECK(pca9555_set_config(
        config_reg.port, CFG_PIN_PWRGOOD | CFG_PIN_INT | CFG_PIN_VCOM_CTRL | CFG_PIN_PWRUP, 1
    ));

    int tries = 0;
    while (!((pca9555_read_input(config_reg.port, 1) & 0xC0) == 0x80)) {
        if (tries >= 50) {
            ESP_LOGE("epdiy", "failed to shut down TPS65185!");
            break;
        }
        tries++;
        vTaskDelay(1);
    }

    // Not sure why we need this delay, but the TPS65185 seems to generate an interrupt after some
    // time that needs to be cleared.
    vTaskDelay(50);
    pca9555_read_input(config_reg.port, 0);
    pca9555_read_input(config_reg.port, 1);
    i2c_driver_delete(EPDIY_I2C_PORT);

    gpio_uninstall_isr_service();
}
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

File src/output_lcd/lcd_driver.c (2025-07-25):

#include "lcd_driver.h"
#include "epdiy.h"

#include "../output_common/render_method.h"
#include "esp_heap_caps.h"
#include "esp_intr_alloc.h"
#include "hal/gpio_types.h"

#ifdef RENDER_METHOD_LCD

#include <assert.h>
#include <esp_idf_version.h>
#include <esp_log.h>
#include <soc/lcd_periph.h>
#include <soc/rmt_periph.h>
#include <stddef.h>
#include <stdint.h>
#include <stdio.h>
#include <string.h>

#include <driver/rmt_tx.h>
#include <driver/rmt_types.h>
#include <driver/rmt_types_legacy.h>
#include <esp_private/periph_ctrl.h>
#include <esp_private/esp_clk.h>
#include <hal/rmt_types.h>
#include <soc/clk_tree_defs.h>

#include <driver/gpio.h>
#include <esp_check.h>
#include <esp_err.h>
#include <esp_lcd_panel_ops.h>
#include <esp_lcd_panel_rgb.h>
#include <esp_private/gdma.h>
#include <esp_timer.h>
#include <freertos/FreeRTOS.h>
#include <freertos/semphr.h>
#include <freertos/task.h>
#include <hal/dma_types.h>
#include <hal/gdma_ll.h>
#include <hal/gpio_hal.h>
#include <hal/lcd_hal.h>
#include <hal/lcd_ll.h>
#include <hal/rmt_ll.h>
#include <rom/cache.h>
#include <soc/lcd_periph.h>
#include <soc/rmt_struct.h>

#define TAG "epdiy"

#if ESP_IDF_VERSION < ESP_IDF_VERSION_VAL(5, 3, 2)
#define LCD_PERIPH_SIGNALS lcd_periph_signals
#else
#define LCD_PERIPH_SIGNALS lcd_periph_rgb_signals
#endif

static inline int min(int x, int y) {
    return x < y ? x : y;
}
static inline int max(int x, int y) {
    return x > y ? x : y;
}

#define S3_LCD_PIN_NUM_BK_LIGHT -1
// #define S3_LCD_PIN_NUM_MODE           4

#define LINE_BATCH 1000
#define BOUNCE_BUF_LINES 4

#define RMT_CKV_CHAN RMT_CHANNEL_1

// The extern line is declared in esp-idf/components/driver/deprecated/rmt_legacy.c. It has access
// to RMTMEM through the rmt_private.h header which we can't access outside the sdk. Declare our own
// extern here to properly use the RMTMEM smybol defined in
// components/soc/[target]/ld/[target].peripherals.ld Also typedef the new rmt_mem_t struct to the
// old rmt_block_mem_t struct. Same data fields, different names
typedef rmt_mem_t rmt_block_mem_t;
extern rmt_block_mem_t RMTMEM;

// spinlock for protecting the critical section at frame start
static portMUX_TYPE frame_start_spinlock = portMUX_INITIALIZER_UNLOCKED;

typedef struct {
    lcd_hal_context_t hal;
    intr_handle_t vsync_intr;
    intr_handle_t done_intr;

    frame_done_func_t frame_done_cb;
    line_cb_func_t line_source_cb;
    void* line_cb_payload;
    void* frame_cb_payload;

    int line_length_us;
    int line_cycles;
    int lcd_res_h;

    LcdEpdConfig_t config;

    uint8_t* bounce_buffer[2];
    // size of a single bounce buffer
    size_t bb_size;
    size_t batches;

    // Number of DMA descriptors that used to carry the frame buffer
    size_t num_dma_nodes;
    // DMA channel handle
    gdma_channel_handle_t dma_chan;
    // DMA descriptors pool
    dma_descriptor_t* dma_nodes;

    /// The number of bytes in a horizontal display register line.
    int line_bytes;

    // With 8 bit bus width, we need a dummy cycle before the actual data,
    // because the LCD peripheral behaves weirdly.
    // Also see:
    // https://blog.adafruit.com/2022/06/14/esp32uesday-hacking-the-esp32-s3-lcd-peripheral/
    int dummy_bytes;

    /// The number of lines of the display
    int display_lines;
} s3_lcd_t;

static s3_lcd_t lcd = { 0 };

void IRAM_ATTR epd_lcd_line_source_cb(line_cb_func_t line_source, void* payload) {
    lcd.line_source_cb = line_source;
    lcd.line_cb_payload = payload;
}

void IRAM_ATTR epd_lcd_frame_done_cb(frame_done_func_t cb, void* payload) {
    lcd.frame_done_cb = cb;
    lcd.frame_cb_payload = payload;
}

static IRAM_ATTR bool fill_bounce_buffer(uint8_t* buffer) {
    bool task_awoken = false;

    for (int i = 0; i < BOUNCE_BUF_LINES; i++) {
        if (lcd.line_source_cb != NULL) {
            // this is strange, with 16 bit need a dummy cycle. But still, the first byte in the
            // FIFO is correct. So we only need a true dummy byte in the FIFO in the 8 bit
            // configuration.
            int buffer_offset = i * (lcd.line_bytes + lcd.dummy_bytes) + (lcd.dummy_bytes % 2);
            task_awoken |= lcd.line_source_cb(lcd.line_cb_payload, &buffer[buffer_offset]);
        } else {
            memset(&buffer[i * lcd.line_bytes], 0x00, lcd.line_bytes);
        }
    }
    return task_awoken;
}

static void start_ckv_cycles(int cycles) {
    rmt_ll_tx_enable_loop_count(&RMT, RMT_CKV_CHAN, true);
    rmt_ll_tx_enable_loop_autostop(&RMT, RMT_CKV_CHAN, true);
    rmt_ll_tx_set_loop_count(&RMT, RMT_CKV_CHAN, cycles);
    rmt_ll_tx_reset_pointer(&RMT, RMT_CKV_CHAN);
    rmt_ll_tx_start(&RMT, RMT_CKV_CHAN);
}

/**
 * Build the RMT signal according to the timing set in the lcd object.
 */
static void ckv_rmt_build_signal() {
    int low_time = (lcd.line_length_us * 10 - lcd.config.ckv_high_time);
    volatile rmt_item32_t* rmt_mem_ptr = &(RMTMEM.chan[RMT_CKV_CHAN].data32[0]);
    rmt_mem_ptr->duration0 = lcd.config.ckv_high_time;
    rmt_mem_ptr->level0 = 1;
    rmt_mem_ptr->duration1 = low_time;
    rmt_mem_ptr->level1 = 0;
    rmt_mem_ptr[1].val = 0;
}

/**
 * Configure the RMT peripheral for use as the CKV clock.
 */
static void init_ckv_rmt() {
    periph_module_reset(PERIPH_RMT_MODULE);
    periph_module_enable(PERIPH_RMT_MODULE);

    rmt_ll_enable_periph_clock(&RMT, true);

    // Divide 80MHz APB Clock by 8 -> .1us resolution delay
    // idf >= 5.0 calculates the clock divider differently
    rmt_ll_set_group_clock_src(&RMT, RMT_CKV_CHAN, RMT_CLK_SRC_DEFAULT, 1, 0, 0);
    rmt_ll_tx_set_channel_clock_div(&RMT, RMT_CKV_CHAN, 8);
    rmt_ll_tx_set_mem_blocks(&RMT, RMT_CKV_CHAN, 2);
    rmt_ll_enable_mem_access_nonfifo(&RMT, true);
    rmt_ll_tx_fix_idle_level(&RMT, RMT_CKV_CHAN, RMT_IDLE_LEVEL_LOW, true);
    rmt_ll_tx_enable_carrier_modulation(&RMT, RMT_CKV_CHAN, false);

    rmt_ll_tx_enable_loop(&RMT, RMT_CKV_CHAN, true);

    gpio_ll_func_sel(GPIO_HAL_GET_HW(GPIO_PORT_0), lcd.config.bus.ckv, PIN_FUNC_GPIO);
    gpio_set_direction(lcd.config.bus.ckv, GPIO_MODE_OUTPUT);
    esp_rom_gpio_connect_out_signal(
        lcd.config.bus.ckv, rmt_periph_signals.groups[0].channels[RMT_CKV_CHAN].tx_sig, false, 0
    );

    ckv_rmt_build_signal();
}

/**
 * Reset the CKV RMT configuration.
 */
static void deinit_ckv_rmt() {
    periph_module_reset(PERIPH_RMT_MODULE);
    periph_module_disable(PERIPH_RMT_MODULE);

    gpio_reset_pin(lcd.config.bus.ckv);
}
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

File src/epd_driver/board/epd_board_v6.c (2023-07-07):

#include "epd_board.h"
#include "../include/board/epd_board_v6.h"

#include "esp_log.h"
#include "../display_ops.h"
#include "../i2s_data_bus.h"
#include "../rmt_pulse.h"
#include "../tps65185.h"
#include "../pca9555.h"

#include <driver/i2c.h>

static int v6_wait_for_interrupt(int timeout) __attribute__((unused));

#define CFG_SCL             GPIO_NUM_33
#define CFG_SDA             GPIO_NUM_32
#define CFG_INTR            GPIO_NUM_35
#define EPDIY_I2C_PORT      I2C_NUM_0
#define CFG_PIN_OE          (PCA_PIN_PC10 >> 8)
#define CFG_PIN_MODE        (PCA_PIN_PC11 >> 8)
#define CFG_PIN_STV         (PCA_PIN_PC12 >> 8)
#define CFG_PIN_PWRUP       (PCA_PIN_PC13 >> 8)
#define CFG_PIN_VCOM_CTRL   (PCA_PIN_PC14 >> 8)
#define CFG_PIN_WAKEUP      (PCA_PIN_PC15 >> 8)
#define CFG_PIN_PWRGOOD     (PCA_PIN_PC16 >> 8)
#define CFG_PIN_INT         (PCA_PIN_PC17 >> 8)
#define D7 GPIO_NUM_23
#define D6 GPIO_NUM_22
#define D5 GPIO_NUM_21
#define D4 GPIO_NUM_19
#define D3 GPIO_NUM_18
#define D2 GPIO_NUM_5
#define D1 GPIO_NUM_4
#define D0 GPIO_NUM_25

/* Control Lines */
#define CKV GPIO_NUM_26
#define STH GPIO_NUM_27

#define V4_LATCH_ENABLE GPIO_NUM_2

/* Edges */
#define CKH GPIO_NUM_15

typedef struct {
    i2c_port_t port;
    bool pwrup;
    bool vcom_ctrl;
    bool wakeup;
    bool others[8];
} epd_config_register_t;

static i2s_bus_config i2s_config = {
  .clock = CKH,
  .start_pulse = STH,
  .data_0 = D0,
  .data_1 = D1,
  .data_2 = D2,
  .data_3 = D3,
  .data_4 = D4,
  .data_5 = D5,
  .data_6 = D6,
  .data_7 = D7,
};

static bool interrupt_done = false;

static void IRAM_ATTR interrupt_handler(void* arg) {
    interrupt_done = true;
}

static int v6_wait_for_interrupt(int timeout) {
  int tries = 0;
  while (!interrupt_done && gpio_get_level(CFG_INTR) == 1) {
    if (tries >= 500) {
        return -1;
    }
    tries++;
    vTaskDelay(1);
  }
  int ival = 0;
  interrupt_done = false;
  pca9555_read_input(EPDIY_I2C_PORT, 1);
  ival = tps_read_register(EPDIY_I2C_PORT, TPS_REG_INT1);
  ival |= tps_read_register(EPDIY_I2C_PORT, TPS_REG_INT2) << 8;
  while (!gpio_get_level(CFG_INTR)) { vTaskDelay(1); }
  return ival;
}

static epd_config_register_t config_reg;

static void epd_board_init(uint32_t epd_row_width) {
  gpio_hold_dis(CKH); // free CKH after wakeup

  i2c_config_t conf;
  conf.mode = I2C_MODE_MASTER;
  conf.sda_io_num = CFG_SDA;
  conf.scl_io_num = CFG_SCL;
  conf.sda_pullup_en = GPIO_PULLUP_ENABLE;
  conf.scl_pullup_en = GPIO_PULLUP_ENABLE;
  conf.master.clk_speed = 400000;
  conf.clk_flags = I2C_SCLK_SRC_FLAG_FOR_NOMAL;
  ESP_ERROR_CHECK(i2c_param_config(EPDIY_I2C_PORT, &conf));

  ESP_ERROR_CHECK(i2c_driver_install(EPDIY_I2C_PORT, I2C_MODE_MASTER, 0, 0, 0));

  config_reg.port = EPDIY_I2C_PORT;
  config_reg.pwrup = false;
  config_reg.vcom_ctrl = false;
  config_reg.wakeup = false;
  for (int i=0; i<8; i++) {
      config_reg.others[i] = false;
  }

  gpio_set_direction(CFG_INTR, GPIO_MODE_INPUT);
  gpio_set_intr_type(CFG_INTR, GPIO_INTR_NEGEDGE);

  ESP_ERROR_CHECK(gpio_install_isr_service(ESP_INTR_FLAG_EDGE));

  ESP_ERROR_CHECK(gpio_isr_handler_add(CFG_INTR, interrupt_handler, (void *) CFG_INTR));

  // set all epdiy lines to output except TPS interrupt + PWR good
  ESP_ERROR_CHECK(pca9555_set_config(config_reg.port, CFG_PIN_PWRGOOD | CFG_PIN_INT, 1));

  // use latch pin as GPIO
  PIN_FUNC_SELECT(GPIO_PIN_MUX_REG[V4_LATCH_ENABLE], PIN_FUNC_GPIO);
  ESP_ERROR_CHECK(gpio_set_direction(V4_LATCH_ENABLE, GPIO_MODE_OUTPUT));
  gpio_set_level(V4_LATCH_ENABLE, 0);

  // Setup I2S
  // add an offset off dummy bytes to allow for enough timing headroom
  i2s_bus_init( &i2s_config, epd_row_width + 32 );

  rmt_pulse_init(CKV);
}

static void epd_board_deinit() {
  //gpio_reset_pin(CFG_INTR);
  //rtc_gpio_isolate(CFG_INTR);

  ESP_ERROR_CHECK(pca9555_set_config(config_reg.port, CFG_PIN_PWRGOOD | CFG_PIN_INT | CFG_PIN_VCOM_CTRL | CFG_PIN_PWRUP, 1));

  int tries = 0;
  while (!((pca9555_read_input(config_reg.port, 1) & 0xC0) == 0x80)) {
    if (tries >= 500) {
      ESP_LOGE("epdiy", "failed to shut down TPS65185!");
      break;
    }
    tries++;
    vTaskDelay(1);
    printf("%X\n", pca9555_read_input(config_reg.port, 1));
  }
  // Not sure why we need this delay, but the TPS65185 seems to generate an interrupt after some time that needs to be cleared.
  vTaskDelay(500);
  pca9555_read_input(config_reg.port, 0);
  pca9555_read_input(config_reg.port, 1);
  ESP_LOGI("epdiy", "going to sleep.");
  i2c_driver_delete(EPDIY_I2C_PORT);
}
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

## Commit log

2021-05-27 Leave in master epdiy component only
    [BOM.csv, FH12-33S-0.5SH.stp, Tactal Switch - SMD (5mmx 5mmx1.5mm).stp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]
2022-02-16 Update to current epdiy master (Except waveforms/epdiy_ED047TC1.h)
2023-07-07 V7 custom 13.3" FPC connector C92280
    [BOM.csv, BOM_lcsc.csv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]
2023-07-07 S3 V7 Schematics
    [BOM_lcsc.xlsx, epaper-breakout.kicad_sch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]
2023-07-08 HW update gerbers & drill map
    [epaper-breakout-NPTH-drl_map.gbr, epaper-breakout-PTH-drl_map.gbr]
2023-08-21 Rev 1.1 v7
    [FH12-33S-0.5SH.step, FH12-33S-0.5SH.stp, TPS651851RSLR.step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]
2023-09-06 Rev 1.1 revised
    [BOM_lcsc.csv, BOM_lcsc.xlsx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]
2023-10-03 Rel. 1.1 55x100
    [L-40xx.STEP, epaper-breakout.kicad_pcb]
2023-10-12 Revision to 1.1 new CDC USB-C
    [epaper-breakout.kicad_pcb, epaper-breakout.kicad_sch]
2023-10-21 Add extension adapter 33 to 34 pins (6")
    [X05A20H34G.step, extension-cable.kicad_pcb, extension-cable.kicad_sch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]
2023-10-22 Add double extension cable PCB
    [X05A20H34G.step, extension-cable.kicad_pcb, extension-cable.kicad_sch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]
2023-10-24 Add PCB tester with LEDs & MicroSD
    [BOM.csv, BOM.xlsx, X05A20H34G.step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]
2023-10-25 40 pin FPC tester sent to fabrication
    [BOM.xlsx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]
2023-10-26 GBRs plus 3D model of PCB
    [BOM.xlsx, BOM_lcsc.xlsx, epaper-breakout.kicad_pcb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]
2025-03-20 Add v7-raw board
    [charger_stepup.kicad_pcb, charger_stepup.sch, partitions.csv]
2025-03-29 Fixes it to 5.3
    [lcd_driver.c]
2025-03-29 Revert "Fixes it to 5.3"
    This reverts commit 591abeaf556c7bb8afb5ce1e9cbb1320bc550a4b.
    [lcd_driver.c]
2025-04-11 Add epdiy_v7_103 board and dragon test
    [partitions.csv]
2025-07-25 Add ESP-IDF 6.0 compatibility fixes
    - Fix GDMA API: gdma_new_channel → gdma_new_ahb_channel
    - Fix GDMA config: gdma_transfer_ability_t → gdma_transfer_config_t
    - Fix GDMA function: gdma_set_transfer_ability → gdma_config_transfer
    - Add RCC atomic environment declarations for LCD HAL functions
    - Resolve compilation errors with ESP-IDF v6.0-dev-1362-g346870a304
    Fixes major compatibility issues for parallel e-paper displays on ESP-IDF 6.0
    [epd_board_common.c, lcd_driver.c]
2025-07-25 Fix ESP-IDF 6.0 compatibility issues
    - Update GDMA API: gdma_new_channel → gdma_new_ahb_channel
    - Update transfer config: gdma_transfer_ability_t → gdma_transfer_config_t
    - Update GPIO HAL: gpio_hal_iomux_func_sel → gpio_ll_func_sel with 3 parameters
    - Update ADC calibration: adc_cali_line_fitting_config_t → adc_cali_curve_fitting_config_t
    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
    [epd_board_common.c, lcd_driver.c]
